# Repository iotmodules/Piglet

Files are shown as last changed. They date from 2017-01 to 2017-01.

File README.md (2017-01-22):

# Piglet - IOT Development Module

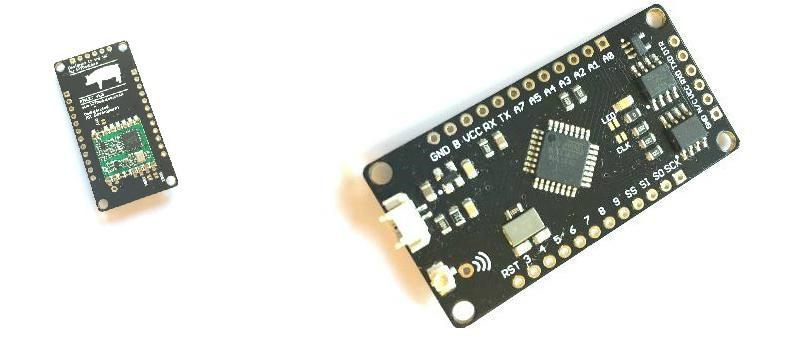
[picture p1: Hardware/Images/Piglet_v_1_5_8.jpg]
Piglet 1.5 Piglet v1.5


#Features of the Piglet IOT development board
 
 * ATMega328-au fully compatible with the Arduino IDE
 * Support for Optiboot and DualOptiboot Bootloaders
 * Extremely low power consumption when asleep typically 8uA
 * External 8Mhz crystal oscillator to allow support for the critical timing required by the LORA radios and the LMIC LoRaWAN Library https://github.com/matthijskooijman/arduino-lmic
 * Precision resistor divider to accurately measure the battery voltage before the regulator
 * Real time clock with temperature compensation to provide a high level of accuaracy for time critical functions such as scheduling of transmissions and timestamping events. 
 * Support for HopeRF HCW69HCW and RFM95 Lora radios 
 * On board EUI-64 unique ID accesible over the I2C bus
 * On board 4Mbit SPI flash for configuration data storage and code updates using DualOptiboot 
 * Precision voltage regulator with quiescent current of only 1ua allowing supply voltages between 2.8v and 6.0v
 * U.FL connector for connection of a range of antenna options

#Licence

CC-BY-SA 4.0 https://creativecommons.org/licenses/by-sa/4.0/ You are free to share and adapt. But you need to give attribution and use the same license to redistribute.

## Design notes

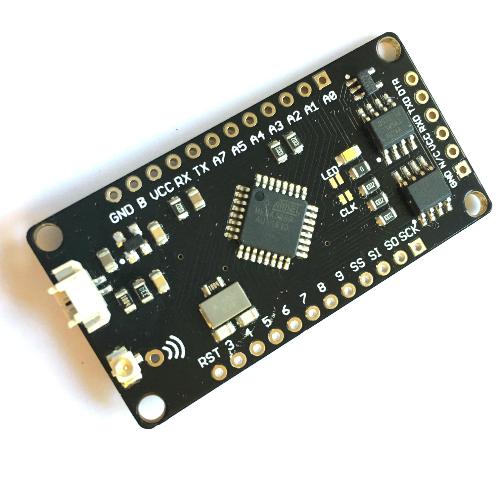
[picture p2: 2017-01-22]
Hardware/Images/Piglet_v_1_5_5.jpg

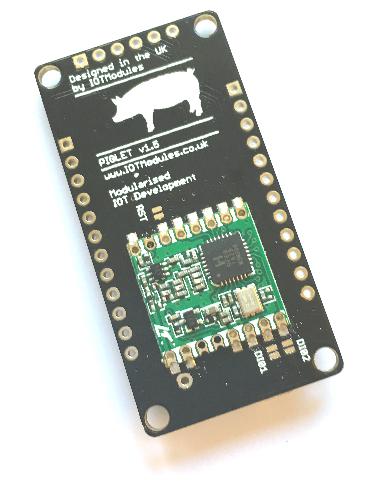
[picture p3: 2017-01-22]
Hardware/Images/Piglet_v_1_5_9.JPG

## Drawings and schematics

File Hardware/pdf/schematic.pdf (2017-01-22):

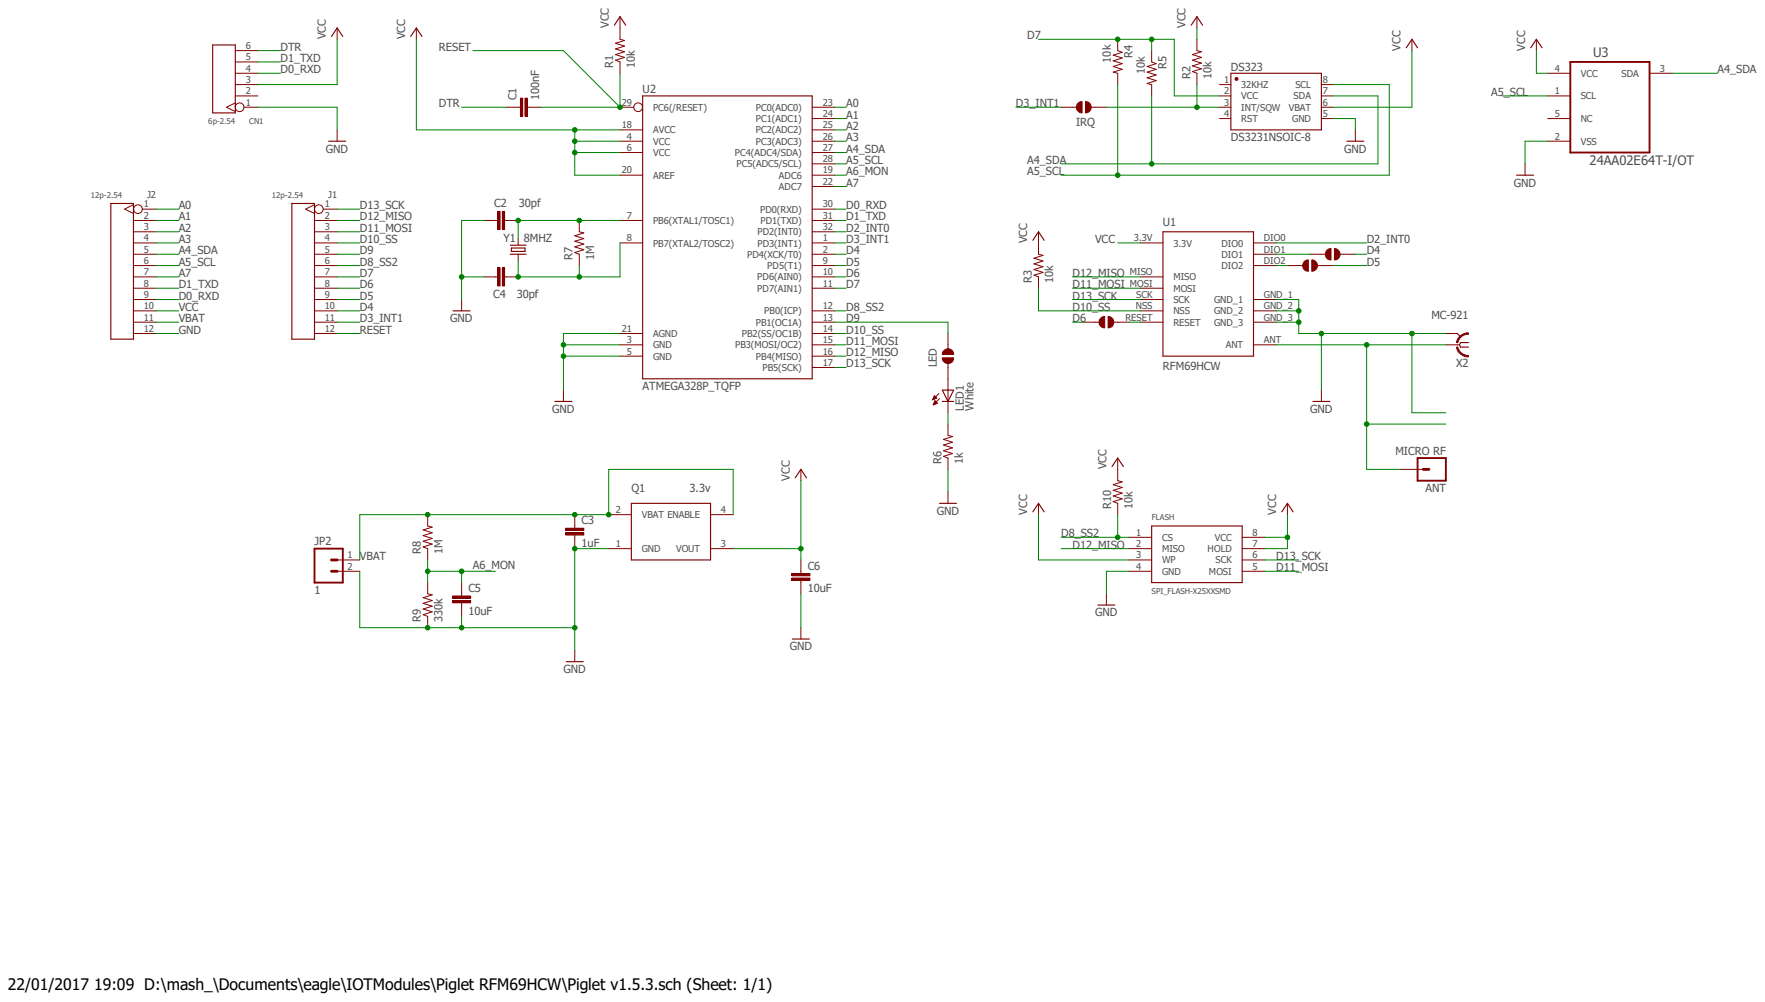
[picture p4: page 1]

MICRO RF ¹⁰k VCC

22/01/2017 19:09 D:\mash_\Documents\eagle\IOTModules\Piglet RFM69HCW\Piglet v1.5.3.sch (Sheet: 1/1)

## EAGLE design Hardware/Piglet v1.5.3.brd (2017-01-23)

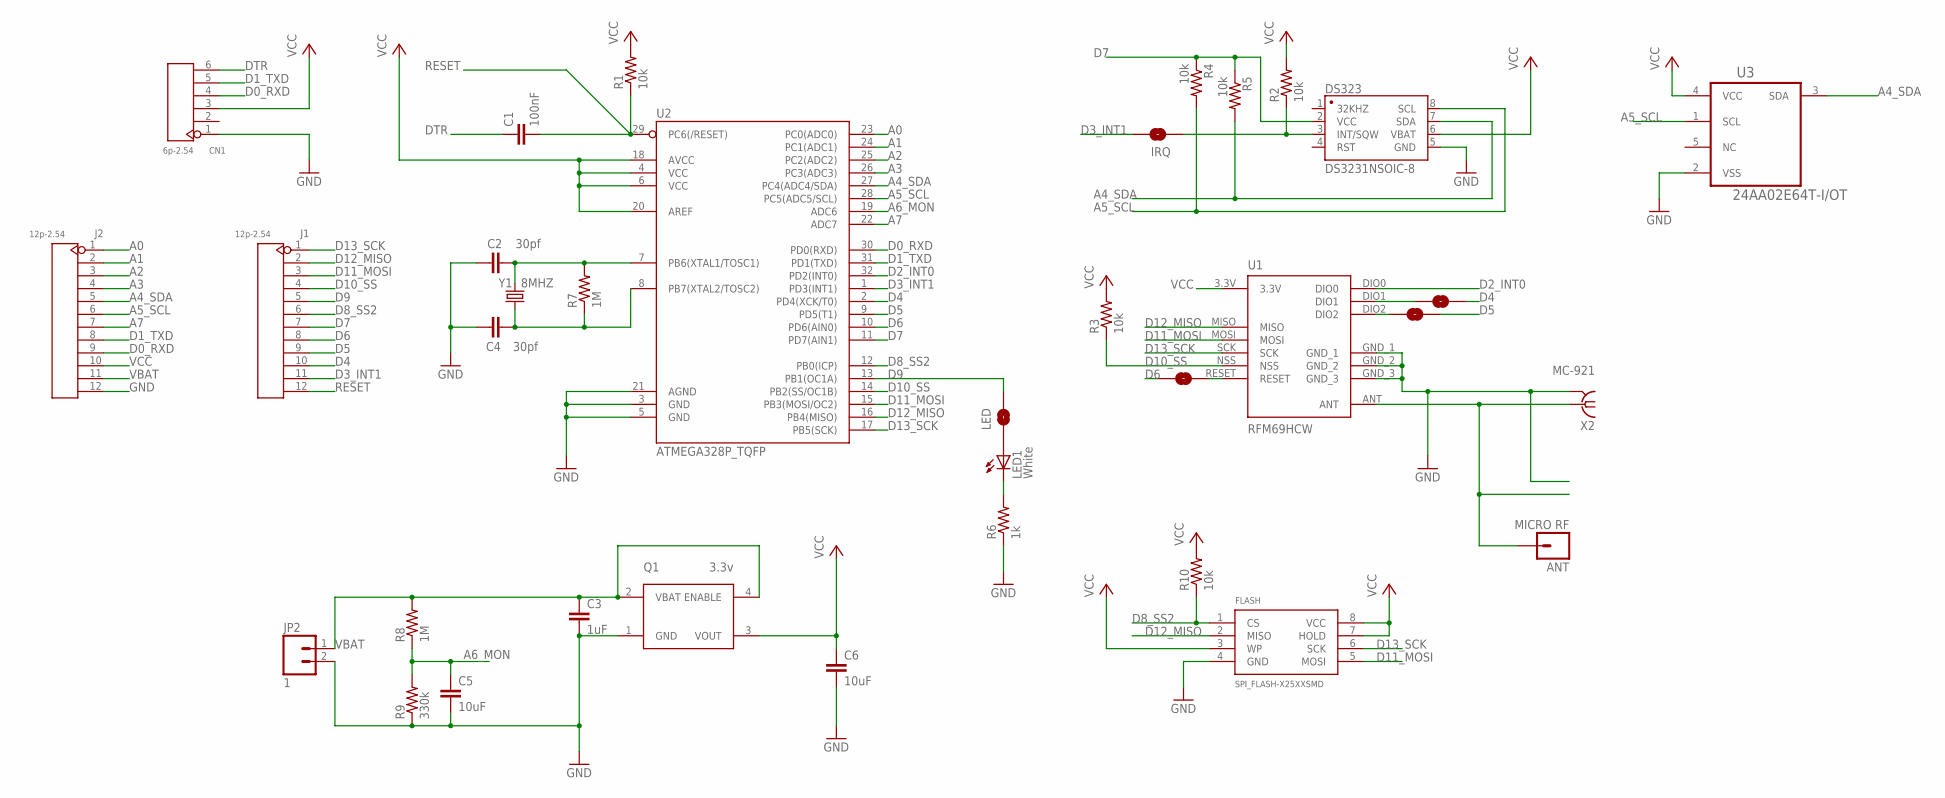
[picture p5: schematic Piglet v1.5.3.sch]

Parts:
ANT: MICRO RF; 1X01
C1: 100nF; 0805
C2, C4: 30pf; 0805
C3: 1uF; 0805
C5, C6: 10uF; 0805
CN1: 6p-2.54; H6-2.54
DS323: DS3231NSOIC-8; DS3231MZ+TRL
FLASH: SPI_FLASH-X25XXSMD; SO08
IRQ, IRQ0, IRQ1, IRQ2: SOLDERJUMPERNO; SJ_2S-NO
J1, J2: 12p-2.54; H12-2.54
JP2: 1; M_JST_90_SMD_2
LED: SOLDERJUMPERNO; SJ_2S-NO
LED1: White; CHIPLED_0805
Q1: 3.3v; SOT143
R1, R2, R3, R4, R5, R10: 10k; 0805
R6: 1k; 0805
R7, R8: 1M; 0805
R9: 330k; 0805
U1: RFM69HCW; RFM69HCW-XXXS2
U2: ATMEGA328P_TQFP; TQFP32-08
U3: 24AA02E64T-I/OT; SOT95P270X145-5N
X2: MC-921
Y1: 8MHZ; CRYSTAL-TXC-7A

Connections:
A0: J2.1, U2.23 (PC0(ADC0))
A1: J2.2, U2.24 (PC1(ADC1))
A2: J2.3, U2.25 (PC2(ADC2))
A3: J2.4, U2.26 (PC3(ADC3))
A4_SDA: DS323.7 (SDA), J2.5, R5.2, U2.27 (PC4(ADC4/SDA)), U3.3 (SDA)
A5_SCL: DS323.8 (SCL), J2.6, R4.2, U2.28 (PC5(ADC5/SCL)), U3.1 (SCL)
A6_MON: C5.1, R8.1, R9.2, U2.19 (ADC6)
A7: J2.7, U2.22 (ADC7)
ANT: ANT.1, U1.ANT, X2.1
D0_RXD: CN1.4, J2.9, U2.30 (PD0(RXD))
D1_TXD: CN1.5, J2.8, U2.31 (PD1(TXD))
D2_INT0: U1.DIO0, U2.32 (PD2(INT0))
D3_INT1: IRQ.2, J1.11, U2.1 (PD3(INT1))
D4: IRQ0.1, J1.10, U2.2 (PD4(XCK/T0))
D5: IRQ2.1, J1.9, U2.9 (PD5(T1))
D6: IRQ1.2, J1.8, U2.10 (PD6(AIN0))
D7: DS323.2 (VCC), J1.7, R4.1, R5.1, U2.11 (PD7(AIN1))
D8_SS2: FLASH.1 (CS), J1.6, R10.1, U2.12 (PB0(ICP))
D9: J1.5, LED.2, U2.13 (PB1(OC1A))
D10_SS: J1.4, R3.1, U1.NSS, U2.14 (PB2(SS/OC1B))
D11_MOSI: FLASH.5 (MOSI), J1.3, U1.MOSI, U2.15 (PB3(MOSI/OC2))
D12_MISO: FLASH.2 (MISO), J1.2, U1.MISO, U2.16 (PB4(MISO))
D13_SCK: FLASH.6 (SCK), J1.1, U1.SCK, U2.17 (PB5(SCK))
DTR: C1.1, CN1.6
GND: C2.1, C3.2, C4.1, C5.2, C6.2, CN1.1, DS323.5 (GND), FLASH.4 (GND), J2.12, JP2.2, Q1.1 (GND), R6.1, R9.1, U1.GND_1, U1.GND_2, U1.GND_3, U2.3 (GND), U2.5 (GND), U2.21 (AGND), U3.2 (VSS), X2.2@1 (GND), X2.2@2 (GND)
unnamed: LED1.C, R6.2
unnamed: IRQ2.2, U1.DIO2
unnamed: DS323.3 (INT/SQW), IRQ.1, R2.1
unnamed: C2.2, R7.2, U2.7 (PB6(XTAL1/TOSC1)), Y1.P$2 (2)
unnamed: C4.2, R7.1, U2.8 (PB7(XTAL2/TOSC2)), Y1.P$1 (1)
unnamed: LED.1, LED1.A
unnamed: IRQ0.2, U1.DIO1
unnamed: IRQ1.1, U1.RESET
RESET: C1.2, J1.12, R1.1, U2.29 (PC6(/RESET))
VBAT: C3.1, J2.11, JP2.1, Q1.2 (VBAT), Q1.4 (ENABLE), R8.2
VCC: C6.1, CN1.3, DS323.6 (VBAT), FLASH.3 (WP), FLASH.7 (HOLD), FLASH.8 (VCC), J2.10, Q1.3 (VOUT), R1.2, R2.2, R3.2, R10.2, U1.3.3V, U2.4 (VCC), U2.6 (VCC), U2.18 (AVCC), U2.20 (AREF), U3.4 (VCC)

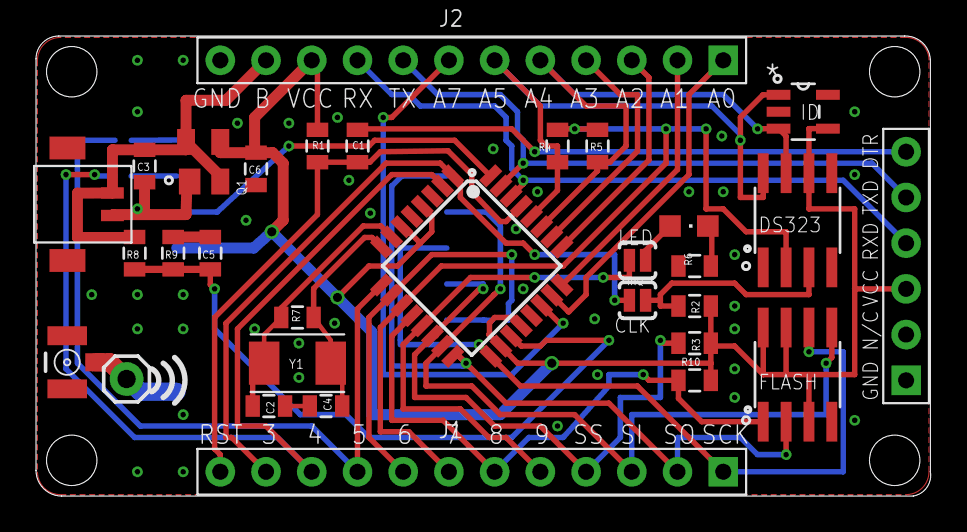
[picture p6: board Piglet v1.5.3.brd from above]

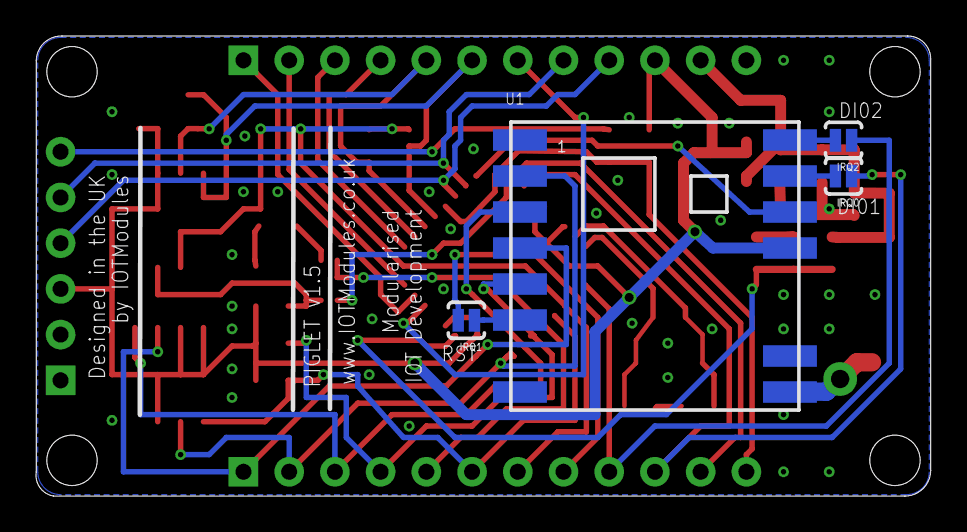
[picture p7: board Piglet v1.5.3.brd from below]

Board: 2 copper layers, 49.7 x 25.6 mm, 35 parts (4 on the bottom side), 36 nets.

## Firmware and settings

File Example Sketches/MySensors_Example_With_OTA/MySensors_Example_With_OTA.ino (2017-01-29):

/**
 * This Arduino sketch is a demonstration of the features of the Piglet IOT development board
 * 
 * ATMega328-au fully compatible with the Arduino IDE
 * 
 * Support for Optiboot and DualOptiboot Bootloaders
 * 
 * Extremeley low power consumption when asleep typically 8uA
 * 
 * External 8Mhz crystal oscillator to allow support for the critical timig required by the 
 * LORA radios and the LMIC LoRaWAN Library https://github.com/matthijskooijman/arduino-lmic
 * 
 * Precision resistor divider to accurately measure the battery voltage before the regulator
 * 
 * Real time clock with temperature compensation to provide hi level of accuaracy for time 
 * critical functions such as scheduling of transmissions and timestamping events.
 * 
 * Support for HopeRF HCW69HCW and RFM95 Lora radios 
 * 
 * On board EUI-64 unique ID accesible over the I2C bus
 * 
 * On board 4Mbit SPI flash for configuration data storage and code updates using DualOptiboot
 *  
 * Precision voltage regulator with quiescent current of only 1ua allowing supply voltages between 2.8v and 6.0v
 * 
 * U.FL connector for connection of a range of antenna options
 * 
 * 
 * 
 * 
 * This example sketch relies heavily on the MySensors Arduino Library created by Tomas Hozza <thozza@gmail.com>
 * 
 * These Libraries can be obtained here https://github.com/mysensors/MySensors
 * 
 * This sketch also requires the libraries indicated below
 *  <DS3232RTC.h>    //http://github.com/JChristensen/DS3232RTC
 *  <TimeLib.h>      //http://playground.arduino.cc/Code/Time
 *  <Wire.h>         //http://arduino.cc/en/Reference/Wire (included with Arduino IDE)
 * 
 * Created by Doug Mahy <doug.mahy@gmail.com>
 * Copyright (C) 2017  Doug Mahy 
 * 
 * This program is free software; you can redistribute it and/or
 * modify it under the terms of the GNU General Public License
 * version 2 as published by the Free Software Foundation.
 */

// Enable debug prints
#define MY_DEBUG

#define MY_BAUD_RATE 38400

#define SKETCH_NAME "Device id not set"
#define SKETCH_MAJOR_VER "0"
#define SKETCH_MINOR_VER "10"

#define MY_RADIO_RFM69
#define MY_IS_RFM69HW
#define MY_RFM69_FREQUENCY RF69_433MHZ  
#define MY_RFM69_NETWORKID     101
#define MY_RF69_IRQ_NUM 0
#define MY_RF69_IRQ_PIN 2

#define MY_PARENT_NODE_ID 0
#define MY_PARENT_NODE_IS_STATIC
#define MY_TRANSPORT_UPLINK_CHECK_DISABLED
#define MY_TRANSPORT_WAIT_READY_MS 1000
#define MY_SLEEP_TRANSPORT_RECONNECT_TIMEOUT_MS 0

#define MY_OTA_FIRMWARE_FEATURE        // Enables OTA (over the air) capability
#define MY_OTA_FLASH_SS 8               // Flash CS (chip select) pin used
#define MY_OTA_FLASH_JDECID 0x1F84
#define OTA_WAIT_PERIOD 200            // Period the loop is paused the loop whilst OTA transmissions are checked
#define FLASH_CONFIG_DATA_LOCATION 0xFFFF0000   

#define I2CADDRESS 0x50
#define EUI64 0xf8
#define PIGLET_I2C_PULLUP_PIN 7

#define INTERRUPT_PIN 3 // interrupt for RTC
#define RTC_CLOCK_PIN 7 //power for the RTC
#define WAKEINTERVAL 5  //interval between wake up times this sets the interval of the RTC alarm

#define LED_PIN 9 //onboard LED

#define SENSOR_DATA_ID  1 
#define SENSOR_DATA_DESCRIPTION  "Piglet Sensor Data"

#include <math.h>
#include <DS3232RTC.h>                  //http://github.com/JChristensen/DS3232RTC
#include <Wire.h>                       //http://arduino.cc/en/Reference/Wire
#include <TimeLib.h>                    //http://playground.arduino.cc/Code/Time
#include <SPI.h>
#include <MySensors.h>

// Some globals 
long lastTime;
long lastRecievedTime;

char cbuf[255];// buffer for bytes to read from memory
byte buf[255]; //buffer for bytes to writ to memory

bool fwUpdateOngoing;
bool transmission_occured = true;
bool doSleep = true;

typedef struct {
   size_t len;
   uint8_t *bytes;
} vdata;

typedef struct { //this structure is to hold the results of the conversion from seconds to hours mins and seconds
   int tHours;
   int tMinutes;
   int tSeconds;
} t_hms;

MyMessage nodeData(SENSOR_DATA_ID, V_CUSTOM);

void setup(void)
{  
  
  pinMode(SCL, INPUT);          //setting these as inputs reduces the power used by 70uA
  pinMode(SDA, INPUT);          //setting these as inputs reduces the power used by 70uA
  pinMode(LED_PIN, OUTPUT);

  // make sure the flash is sleeping to save power. Investigate if needed though
  if (!_flash.initialize()){
    sendSketchInfo(SKETCH_NAME, SKETCH_MAJOR_VER "." SKETCH_MINOR_VER); 
  }
  else{
    _flash.sleep();
  }
  
  analogReference(EXTERNAL);    //uses the external 2.7v voltage reference from the texas regulator ths is very accurate
  initAlarm(); //initialise the alarm

}

void presentation(){
    // Send the Sketch Version Information to the Gateway
    sendSketchInfo(getEUI64(), SKETCH_MAJOR_VER "." SKETCH_MINOR_VER);
    // Register all sensors to gw (they will be created as child devices)
    present(SENSOR_DATA_ID, S_CUSTOM, SENSOR_DATA_DESCRIPTION, false);// Register all sensors to gw (they will be created as single child device)
    
    requestTime();  //get the server time to update the onboard RTC
    wait(400);  // needed to wait for time to be returned
}

void receiveTime(unsigned long time) {  // This is called when a new time value was received
  lastRecievedTime = time;
}

void receive(const MyMessage &message) {

  if ((message.command_ack_payload == C_SET) && (message.type==V_TEXT)) {
    
       if (_flash.initialize()){ }
       String mystring;
       _flash.blockErase4K(FLASH_CONFIG_DATA_LOCATION);
       while(_flash.busy());
       mystring = message.getString();
      
       mystring.getBytes(buf,255);
       _flash.writeBytes(FLASH_CONFIG_DATA_LOCATION,buf,255);
       while ( _flash.busy() ) {}
       _flash.sleep();
       presentation();
     
  }
}


void loop() {
  if (fwUpdateOngoing) {
    fwUpdateOngoing = false;
    fwUpdateOngoing = wait(OTA_WAIT_PERIOD, C_STREAM, ST_FIRMWARE_RESPONSE);
  } else {
    normalFlow();
  }
}


void normalFlow(void) {

  digitalWrite(LED_PIN, HIGH);
  if (lastTime != lastRecievedTime){  //update time if required
    writeTime(lastRecievedTime);
    lastTime = lastRecievedTime;
  }
  setAlarm(WAKEINTERVAL); //set alarm to trigger again in x seconds time
  
  float voltage =  getBatteryVoltage();   //get the battery voltage convert adc value to voltage using internal reference and bridge ratio
  uint8_t batLevel = (1-((4.1-voltage)/(4.1-2.8)))*100; //do conversion to % range 4.1 full 2.8 empty
 
  String data = String(batLevel) + "," + String(voltage) +  "," +  String(getTemp())+  "," +  String(getTime());
  char buf[26];data.toCharArray(buf, 26);
  
  send(nodeData.set(buf));

  //wait(200);
  //sendHeartbeat();
  if (doSleep){
    
    //wait(100); // now done with fwUpdateOngoing lne instead
    fwUpdateOngoing = wait(OTA_WAIT_PERIOD, C_STREAM, ST_FIRMWARE_RESPONSE); // also acts as delay to wait for other internal messages to arrive such as reboot and present before sleeping
    
    digitalWrite(LED_PIN, LOW);
    sleep(digitalPinToInterrupt(INTERRUPT_PIN),FALLING,0); 
    //smartSleep(digitalPinToInterrupt(INTERRUPT_PIN),FALLING,0);
  
  }
  else {
    digitalWrite(LED_PIN, LOW);
    wait(10000);
  }
}





//====================================================================================================================================================//


float getBatteryVoltage(){

  //convert adc value to voltage using internal reference and bridge ratio
  int aValue = analogRead(A6);
  // need to check all delays and reduce to minimums  
  //delay(100);
  float ref = ((2.7/1023.0000)*(aValue));
  float correction = 4.24/4.24;
  ref = ref*correction;
  float ratio = ((1000.00+330.00)/330.00);
  float bVoltage = ref*ratio;
  return bVoltage;

}

char* getEUI64(){
    //enable pullups on piglet
    pinMode(PIGLET_I2C_PULLUP_PIN,OUTPUT);
    digitalWrite(PIGLET_I2C_PULLUP_PIN,HIGH);
    Wire.beginTransmission(I2CADDRESS);
    Wire.write(EUI64);
    Wire.endTransmission();
    Wire.requestFrom(I2CADDRESS, 8);

    byte *eui64;eui64 = (byte *)malloc(8);
    int i=0;
    while (Wire.available()){
     eui64[i] = Wire.read();i=i+1;
    }
    vdata inData; inData.len = 8; inData.bytes = eui64;
    return vdata_get_hex(inData);
    digitalWrite(PIGLET_I2C_PULLUP_PIN,LOW);
}

char* vdata_get_hex(const vdata data)
{
   char hex_str[]= "0123456789abcdef";

   char* out;
   out = (char *)malloc(data.len * 2 + 1);
   (out)[data.len * 2] = 0;
   
   if (!data.len) return NULL;
   
   for (size_t i = 0; i < data.len; i++) {
      (out)[i * 2 + 0] = hex_str[(data.bytes[i] >> 4) & 0x0F];
      (out)[i * 2 + 1] = hex_str[(data.bytes[i]     ) & 0x0F];
   }
   return out;
}

bool rtcTrigger = true; //setup trigger initially to get the alarm going

t_hms setAlarm(long inSecondsTime){
  rtcTrigger = false; //reset the interrupt trigger
  digitalWrite(RTC_CLOCK_PIN, HIGH); //power up the clock
  RTC.alarm(ALARM_1); // reset the alarm
  time_t t = RTC.get();  // get the time
  long totalSeconds = (long(hour(t)) * 60 * 60)+ (long(minute(t)) * 60) + long(second(t)) + inSecondsTime;  //calculate second to wake up on
  t_hms ts = convertHMS(totalSeconds); // calculate wakeup time in hours minutes and seconds
  RTC.setAlarm(ALM1_MATCH_HOURS , ts.tSeconds, ts.tMinutes, ts.tHours, 0); //set the alarm
  digitalWrite(RTC_CLOCK_PIN, LOW); //sleep the rt clock to save power
  return ts;  
}

void initAlarm(){
  
  pinMode(RTC_CLOCK_PIN, OUTPUT);
  digitalWrite(RTC_CLOCK_PIN, HIGH);          // powers up rtc clock
  RTC.squareWave(SQWAVE_NONE);                // no square wave
  RTC.alarmInterrupt(ALARM_2, false);         // disables alarm 2
  RTC.alarmInterrupt(ALARM_1, true);          // This alarm has resolution in seconds
  RTC.setAlarm(ALM1_MATCH_HOURS, 0, 0, 0, 0); // match alarm when hours mins and seconds match so longest sleep duration is 24 hours
  digitalWrite(RTC_CLOCK_PIN, LOW);           // puts the RTC into sleep mode and saves power
  
}

t_hms convertHMS(long tSec){
   if (tSec >= 86400) tSec = tSec - 86400;
   int remainder = tSec % (60*60);
   int tHours = (tSec - (remainder))/(60*60);
   int tSeconds = remainder % 60;
   int tMinutes = (remainder - tSeconds)/60;
   t_hms out;
   out.tHours = tHours;
   out.tMinutes = tMinutes;
   out.tSeconds = tSeconds;
   return out;
}

char* getTime(){

  char timeBuff[30];
  digitalWrite(RTC_CLOCK_PIN, HIGH);  //turn on real time clock dont forget to turn on before using
  time_t t = RTC.get(); //get the time
  timeFormat(t).toCharArray(timeBuff, 30);  //format into a readable time and date
  digitalWrite(RTC_CLOCK_PIN, LOW); // puts the RTC into sleep mode and saves power
  return timeBuff;
  
}

void writeTime(long timeInSeconds){
  digitalWrite(RTC_CLOCK_PIN, HIGH);  
  RTC.set(timeInSeconds);
  digitalWrite(RTC_CLOCK_PIN, LOW);  
}

float getTemp(){

  digitalWrite(RTC_CLOCK_PIN, HIGH); 
  int tp = RTC.temperature(); //get the temp
  float celsius = tp / 4.0; //do conversion to degrees centigrade
  digitalWrite(RTC_CLOCK_PIN, HIGH); 
  return celsius;
  
}

String timeFormat(time_t t) {
  String timeString = String(hour(t)) + printDigits(minute(t)) + printDigits(second(t)) + " " + String(day(t)) + " " + String(month(t)) + " " + String(year(t));
  return timeString;
}

String printDigits(int digits) {
  String x = ":";
  if (digits < 10) {
    x = x + "0";
  }
  x = x + String(digits);
  return x;
}

                             

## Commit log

2017-01-22 Demonstration of the use of the EUI Unique ID for the Piglet v1.5
    Arduino ketch that outputs to the serial port the unique ID of the
    attached piglet.
2017-01-22 Demonstration of the use of the DS3232 real time clock on the Piglet v1.5
    Arduino sketch that outputs to the serial port the time set in setup the
    alarm time and the temperature
2017-01-22 Battery Monitor Example for the Piglet v1.5
    Arduino sketch that reads battery voltage and battery percentage and
    outputs to the serial port
2017-01-22 Updated battery monitor to use external reference
    Using external reference from voltage regulator
2017-01-22 Adding Gerber files
    [Piglet v1.5.3.GBL, Piglet v1.5.3.GBO, Piglet v1.5.3.GBP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]
2017-01-22 Board Files
    [Piglet v1.5.3.GBL, Piglet v1.5.3.GBO, Piglet v1.5.3.GBP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]
2017-01-23 Adding Hardware Files
    [Piglet v1.5.3.GBL, Piglet v1.5.3.GBO, Piglet v1.5.3.GBP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]
2017-01-29 Battery Drain Issue When Lost Connection
    Changed to using static node id
    [MySensors_Example_With_OTA.ino]
2017-01-29 Battery Dran ods

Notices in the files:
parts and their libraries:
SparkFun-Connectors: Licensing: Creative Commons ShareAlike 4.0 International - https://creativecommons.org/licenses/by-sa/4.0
